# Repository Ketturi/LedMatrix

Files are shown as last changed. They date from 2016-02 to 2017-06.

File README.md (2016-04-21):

# LedMatrix
128x10 LED matrix IoT display.

ESP8266 WiFi module controls daisychained 32x10 led display units.
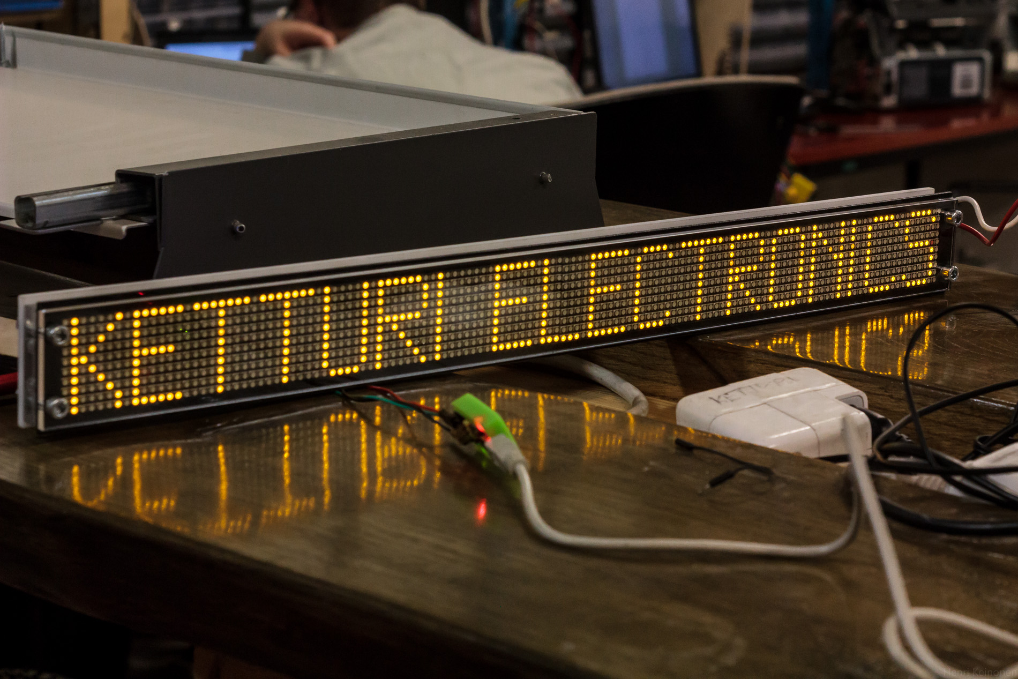
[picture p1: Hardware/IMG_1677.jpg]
Display


## Hardware
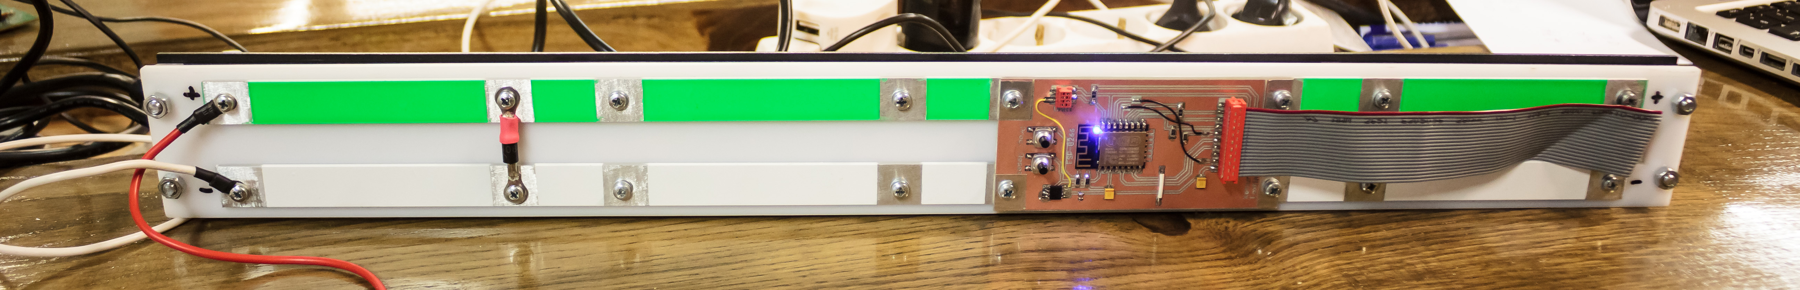
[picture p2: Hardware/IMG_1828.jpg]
Display Backside

Custom build enclosure to hold four display modules, their interlinking cables, power busbars and controller board together. Acrylic parts are lasercut from dxf images designed in Autodesk Fusion360.
[3D CAD Model in A360](http://a360.co/1Sen1dj).

[Control board](https://github.com/Ketturi/LedMatrix/tree/master/Hardware/ControlPCB) for connectinc ESP8266 module to display modules is designed in eagle and is made by milling it with CNC routter. 
Display modules are connected to ESP8266 with high speed SPI for matrix column data, and 4 parallel lines for matrix row address.
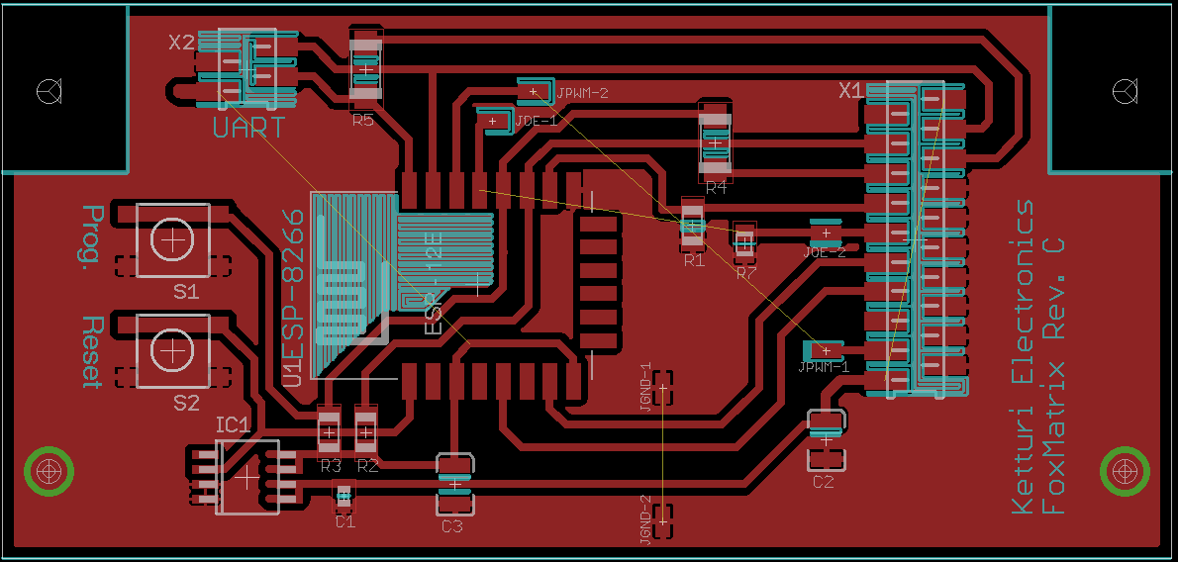
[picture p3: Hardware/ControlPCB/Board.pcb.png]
Control board

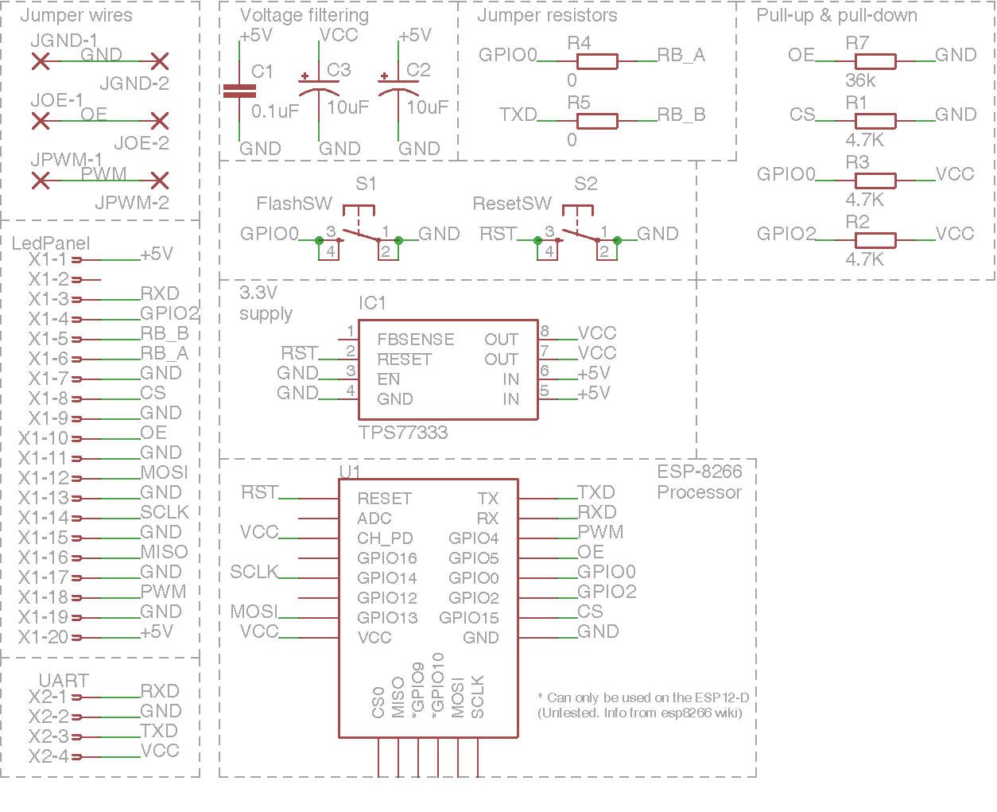
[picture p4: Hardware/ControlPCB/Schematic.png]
Schematics

Display modules used in this single prototype are propriety, and do not contain make or model. There is no other available information of these, and all work here is done trough reverse engineering.
Code and control board is easily adaptable to publicly obtainable LED matrix displays.

## Software
ESP8266 module runs arduino sketch. Arduino IDE needs [Board core files](https://github.com/esp8266/Arduino) to be able to compile software for module.
Use the arduino.org IDE 1.7.9! Arduino.cc IDE is not working due issues with arduino-builder. You need to install board files and libraries manually.

Simple function converts binary bitmap data to column data corresponding selected row and column. Data is then transferred trough SPI to column led drivers (32 bit shift register in each module daisychained together)
Row is selected trough 4-bit address. 

### ESP8266 spesific features
#### OTA Update
Software incorporates [OTA updates](http://esp8266.github.io/Arduino/versions/2.1.0/doc/ota_updates/ota_updates.html) through Arduino IDE. When ESP8266 is connected to same network as computer containing IDE, board shows in port menu.
#### WiFi Manager
ESP8266 uses [WiFi Manager](https://github.com/tzapu/WiFiManager) library that allows modifying wlan credentials and other settings without recompiling and uploading the software.
When control board is powered, it tries to connect previously saved WiFi access point. If that however fails, ESP8266 creates access point itself. By connecting this access point user can go to http://192.168.4.1 address and input their own WiFi credentials.
Credentials are saved to flash, and ESP8266 tries to connect that access point. After successful connection display is initialized and starts to show data.
### Arduino IDE board settings

| Setting | Option | Explanaition |
| --- | --- |  --- |
| Board | Generic ESP8266 Module |Install board from http://github.com/esp8266/Arduino
| Flash Mode | QIO |Selects how flash is controlled, QIO = 4 data lines
| Flash Size | 4M (1M SPIFFS) |4MB flash IC, 1M file system (3MB for scetch&OTA)
| Debug port | Disabled |Disables serial debug, serial lines used for data lines
| Debug level | None |No debuging
| Reset Method | ck |Does not matter, no serial programming reset ability
| Flash Frequency | 40Mhz |Probably 40Mhz, 80Mhz should be carefully tested
| Upload Using | OTA |Updated over network
| CPU Frequency | 160Mhz |Speed boost for faster display
| Upload SPEED | 115200| Does not matter when using OTA
| Port | FoxMatrix at <ip> (Generic ESP8266 Module) |Select device from network, shows only when properly connected and discovered

###Kukkaconvert
Kukkaconvert.exe is small windows command line utility for converting PNG images to bitmap binary data for display.
"kukkaconvert.exe image.png" accepts 12 pixel high png black and white images and outputs binary data to output.txt file.

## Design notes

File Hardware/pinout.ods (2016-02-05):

1 | Logic Supply | 5V+ out
2 | ??? | N/C
3 | 1G1+2G2A | Multiplex bit 4 | Rows 0-11
4 | C | Multiplex bit 3 | 1-10 usable
5 | B | Multiplex bit 2
6 | A | Multiplex bit 1
7 | GND
8 | Latch Enable | Shift register chain
9 | GND | 32 bits per board.
10 | Output Enable | 128 bits per 4 boards.
11 | GND
12 | Serial data in
13 | GND
14 | Clock
15 | GND
16 | Feedback | Serial out from last panel
17 | GND
18 | Intensity | PWM
19 | GND
20 | Logic Supply | 5V+ out

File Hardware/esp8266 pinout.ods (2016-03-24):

GPIO | Assigned | Boot function | Function
0 | RB_A | BOOT FLASHSW | FUNCTION_0
1 | RB_B | TXD BOOT | FUNCTION_3
2 | RB_C | BOOT HIGH | FUNCTION_0
3 | RB_D | RXD BOOT | FUNCTION_3
4 | PWM |  | FUNCTION_0
5 | OE |  | FUNCTION_0
6 | Unusable
7 | Unusable
8 | Unusable
9 | Unusable
10 | Unusable
11 | Unusable
12
13 | HSPI MOSI |  | FUNCTION_2
14 | HSPI SCLK |  | FUNCTION_2
15 | HSPI CS | BOOT HIGH | FUNCTION_2
16

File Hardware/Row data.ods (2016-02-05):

Data / Out | 0 | 1 | 2 | 3 | 4 | 5 | 6 | 7 | 8 | 9 | 10 | 11 | 12 | 13 | 14 | 15 | Rivi
0 | H | H | H | H | X | X | X | X | L | H | H | H | H | H | H | H | 1 | Missing leds
1 | H | H | H | H | X | X | X | X | H | L | H | H | H | H | H | H | 2 | first row
10 | H | H | H | H | X | X | X | X | H | H | L | H | H | H | H | H | 3
11 | H | H | H | H | X | X | X | X | H | H | H | L | H | H | H | H | 4
100 | H | H | H | H | X | X | X | X | H | H | H | H | L | H | H | H | 5
101 | H | H | H | H | X | X | X | X | H | H | H | H | H | L | H | H | 6
110 | H | H | H | H | X | X | X | X | H | H | H | H | H | H | L | H | 7
111 | H | H | H | H | X | X | X | X | H | H | H | H | H | H | H | L | 8
1000 | L | H | H | H | X | X | X | X | H | H | H | H | H | H | H | H | 9
1001 | H | L | H | H | X | X | X | X | H | H | H | H | H | H | H | H | 10
1010 | H | H | L | H | X | X | X | X | H | H | H | H | H | H | H | H | 11 | last row
1011 | H | H | H | L | X | X | X | X | H | H | H | H | H | H | H | H | 12 | Missing leds
1100 | H | H | H | H | X | X | X | X | H | H | H | H | H | H | H | H
1101 | H | H | H | H | X | X | X | X | H | H | H | H | H | H | H | H
1110 | H | H | H | H | X | X | X | X | H | H | H | H | H | H | H | H
1111 | H | H | H | H | X | X | X | X | H | H | H | H | H | H | H | H

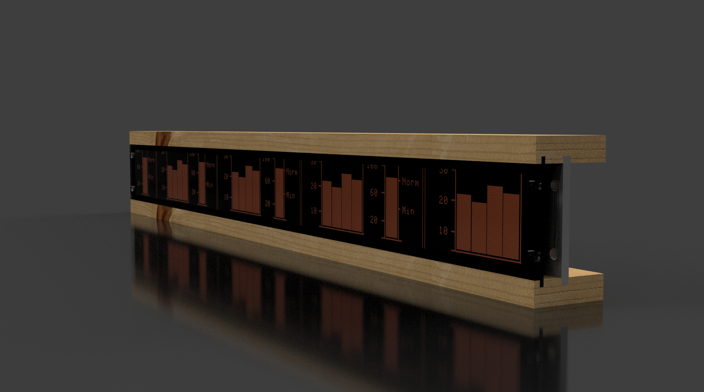
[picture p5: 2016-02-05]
Hardware/Case/Led matrix v2.png

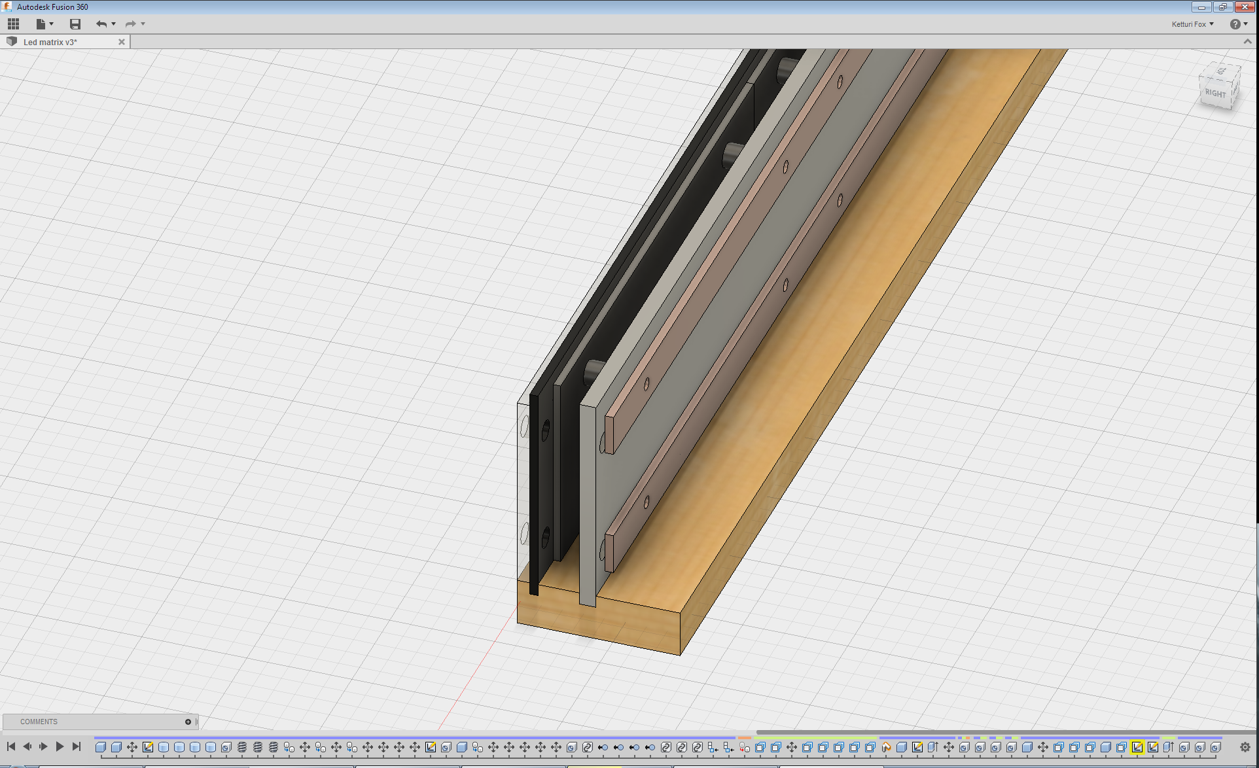
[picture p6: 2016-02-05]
Hardware/Case/Screenshot 2016-01-26 11.06.32.png

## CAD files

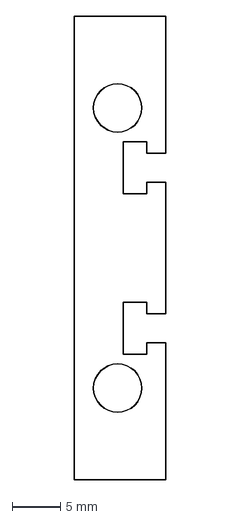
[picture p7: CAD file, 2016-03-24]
Hardware/Case/Spacer.dxf
9.50 x 48.0 mm

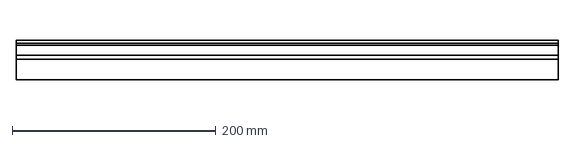
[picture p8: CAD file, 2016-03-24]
Hardware/Case/Board.dxf
532.0 x 38.8 mm

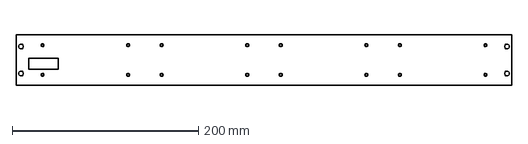
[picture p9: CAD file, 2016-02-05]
Hardware/Case/Back plate.dxf
532.0 x 54.0 mm

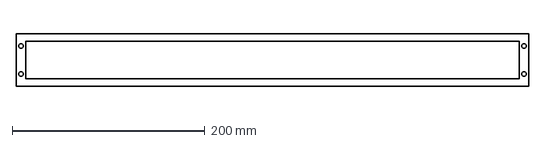
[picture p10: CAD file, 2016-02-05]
Hardware/Case/Mid plate.dxf
532.0 x 54.0 mm

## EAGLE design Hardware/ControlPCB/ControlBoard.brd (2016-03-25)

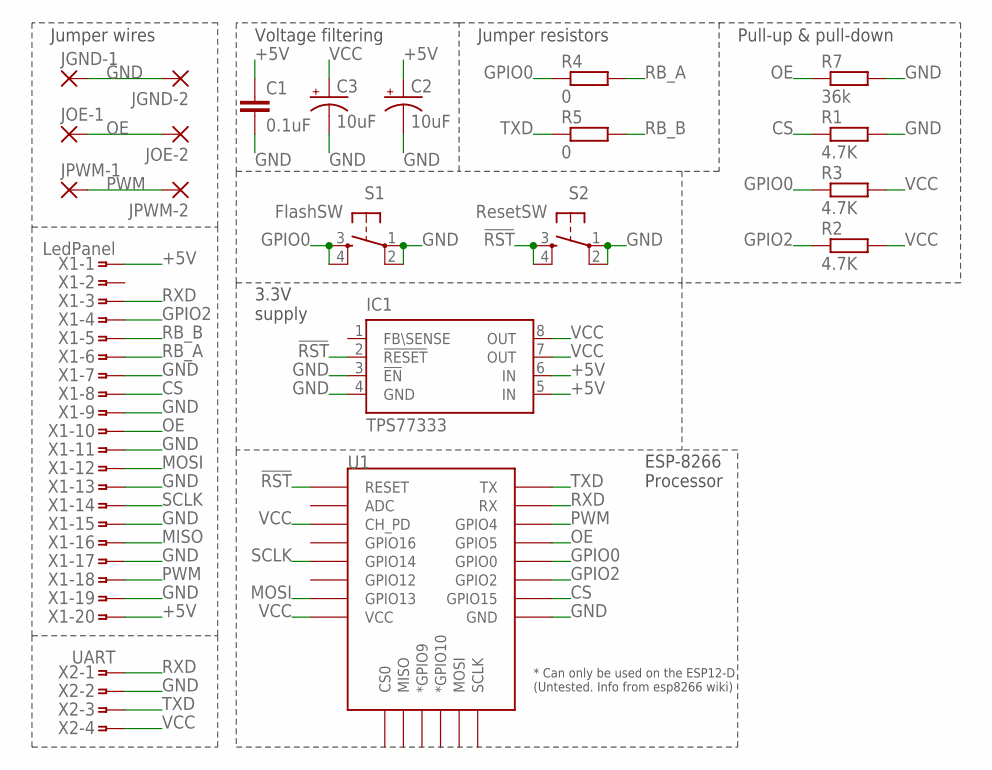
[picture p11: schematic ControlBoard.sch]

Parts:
C1: 0.1uF; 0603-CAP
C2, C3: 10uF; EIA3528
IC1: TPS77333; SOP-08
JGND-1, JGND-2: SMD2; SMD1,27-2,54
JOE-1, JOE-2: SMD2; SMD1,27-2,54
JPWM-1, JPWM-2: SMD2; SMD1,27-2,54
R1, R2, R3: 4.7K; R1206
R4, R5: 0; R5025W
R7: 36k; M2012
S1: FlashSW; DTSM-6
S2: ResetSW; DTSM-6
U1: ESP12ESMD; ESP12E-SMD
X1: LedPanel; SMDTOP20
X2: UART; SMDTOP4

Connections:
!RST: IC1.2 (!RESET), S2.3, S2.4, U1.RESET
+5V: C1.1, C2.A (+), IC1.5 (IN), IC1.6 (IN), X1.1, X1.20
CS: R1.1, U1.GPIO15, X1.8
GND: C1.2, C2.C (-), C3.C (-), IC1.3 (!EN), IC1.4 (GND), JGND-1.1, JGND-2.1, R1.2, R7.2, S1.1, S1.2, S2.1, S2.2, U1.GND, X1.7, X1.9, X1.11, X1.13, X1.15, X1.17, X1.19, X2.2
GPIO0: R3.1, R4.1, S1.3, S1.4, U1.GPIO0
GPIO2: R2.1, U1.GPIO2, X1.4
MISO: X1.16
MOSI: U1.GPIO13, X1.12
OE: JOE-1.1, JOE-2.1, R7.1, U1.GPIO5, X1.10
PWM: JPWM-1.1, JPWM-2.1, U1.GPIO4, X1.18
RB_A: R4.2, X1.6
RB_B: R5.2, X1.5
RXD: U1.RXD0 (RX), X1.3, X2.1
SCLK: U1.GPIO14, X1.14
TXD: R5.1, U1.TXD0 (TX), X2.3
VCC: C3.A (+), IC1.7 (OUT), IC1.8 (OUT), R2.2, R3.2, U1.CH_PD, U1.VCC, X2.4

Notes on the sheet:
Jumper wires
Voltage filtering
Jumper resistors
Pull-up & pull-down
3.3V supply
ESP-8266 Processor

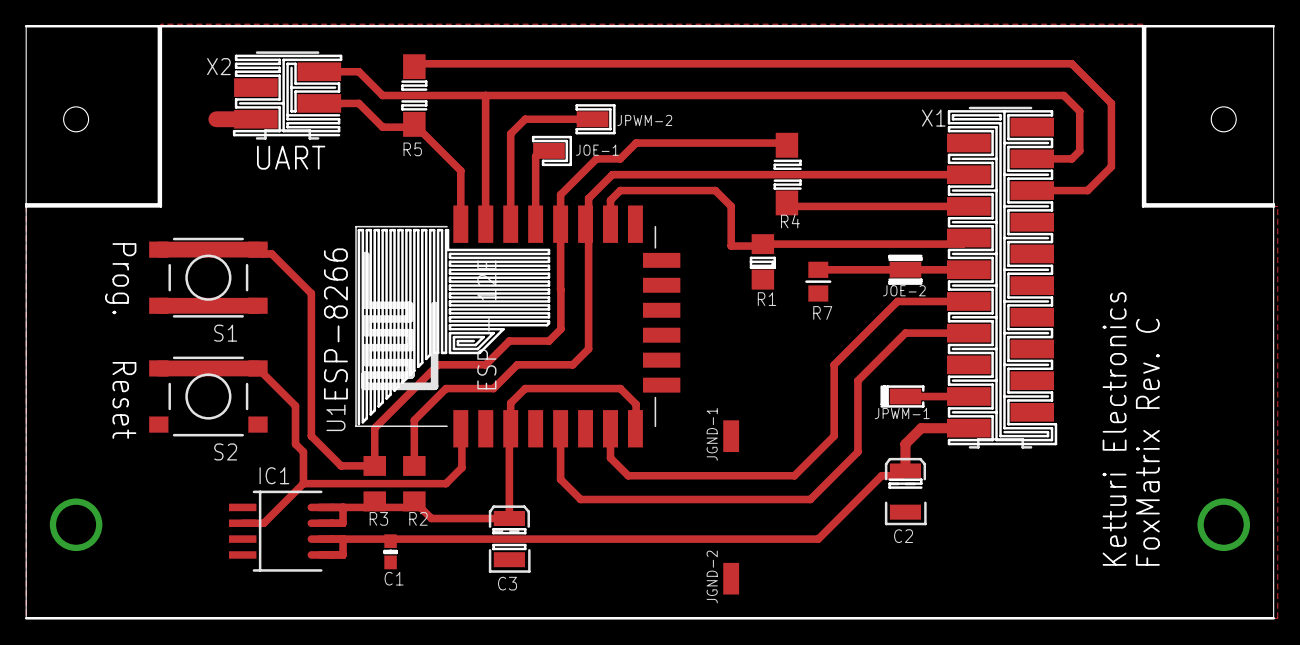
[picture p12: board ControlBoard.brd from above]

Board: 2 copper layers, 100.0 x 47.5 mm, 21 parts (0 on the bottom side), 15 nets.

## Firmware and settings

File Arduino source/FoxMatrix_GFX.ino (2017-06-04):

/*Led matrix IoT controller
  128x10 (four 32x10 linked modules) led matrix display
  controlled with 4bit row select lines and 32bit line shift register.
  ESP8266 (ESP-12F module) as internet enabled application processor
  http://esp8266.github.io/Arduino/versions/2.1.0/doc/reference.html
  Ketturi 2016
*/

#include <Arduino.h>
extern "C" {
#include "user_interface.h"
}
#include <Adafruit_GFX.h>
#include "display.h" //FoxMatrix LED display library

//Font for display
#include "FoxFont.h"
#define font &FoxFont
#define textPos 9 //Vertical position for font

//Bitmaps for symbols
#include "Bitmaps.h"

//Configure display
FoxMatrix screen(10, 128, false); //(height, width, double_buffering)

//Interrupt for display refresh, needs to be polled often
os_timer_t updateTimer;
void ICACHE_RAM_ATTR INT_handler(void *pArg) {
  screen.updateDisplay();
}

#include <Ticker.h> //Ticker for scheduling display stuff
Ticker scheduler;
Ticker busupdater;
Ticker message;

int count = 0;
int page = 0;
bool msgWait = false;
int lastpage = 2;
int pageDelay = 10; //Seconds between display page changes

#define NYSSEPAGE 1
#define CLOCKPAGE 0
#define HEAPPAGE 2

//NTP time
#define NTP_ADDRS "172.20.1.1" //Local NTP server, it's polled quite often so public NTP is not to be used if possible
#include <TimeLib.h>
#include <NtpClientLib.h>

#include "wifi_handler.h"
#include "busstop.h"

BusStop nysse("0501"); //Calls TKL api and sets monitored stop.
int nyssescroller = 0;

void setup() {
  pinMode(16, SPECIAL); //Set GPIO16 to default function, controls reset

  screen.begin(); //Starts display routine

  screen.selectRow(2); //Debug, tells that display is initialized
  delay(100);

  screen.fillScreen(0); //Empty buffer

  os_timer_setfn(&updateTimer, INT_handler, NULL); //set sw timer interupt callback
  os_timer_arm(&updateTimer, 2, true); //Start timer, at this time display starts to show data from framebuffer

  screen.setTextWrap(false);

  screen.setTextSize(1);
  screen.setFont(font);
  screen.setTextColor(1);
  screen.setCursor(0, textPos);
  screen.print("ESP8266 WifiDisplay");

  delay(1000);

  //Wifi
  WiFi.persistent(true);
  setWiFi(); //Starts wifi routines
  wificallbacks(); //Enables wifi messages to display
  otaUpdate(); //Enable ota updates

  NTP.begin(NTP_ADDRS, 2, true); //Initializes NTP connection
  NTP.setInterval(600); //Update NTP time every 10 minutes (ESP8266 is inaccurate at timekeeping)
  ntpCallback(); //Enables NTP messages on screen

  screen.setCursor(0, textPos);
  scheduler.attach(10, changePage);
  busupdater.attach(60, updateBusData);
  nysse.updateBuffer();
}

void loop() { //loops constantly
  ArduinoOTA.handle();

  while ( WiFi.status() == WL_CONNECTED) {
    if (msgWait == false) {
      switch (page) {
        case HEAPPAGE:
          screen.fillScreen(0);
          screen.drawBitmap(0, 0, BitmapInfo, 16, 10, 1);
          screen.setCursor(12, textPos);
          screen.print("Free heap: ");
          screen.print(system_get_free_heap_size());
          screen.print("B");
          break;
        case NYSSEPAGE:
          screen.fillScreen(0);
          screen.drawBitmap(0, 0, BitmapBus, 16, 10, 1);
          screen.setCursor(12, textPos);
          screen.print("Bus ");
          screen.print(nysse.returnLine(nyssescroller));
          screen.drawBitmap(44, 0, BitmapClock, 16, 10, 1);
          screen.setCursor(56, textPos);
          screen.print((nysse.returnTime(nyssescroller) - now()) / 60);
          screen.print(" min");
          break;
        case CLOCKPAGE:
          screen.fillScreen(0);
          screen.drawBitmap(0, 0, BitmapClock, 16, 10, 1);
          screen.setCursor(12, textPos);
          screen.print(NTP.getTimeStr());
          screen.drawBitmap(54, 0, BitmapCalendar, 16, 10, 1);
          screen.setCursor(66, textPos);
          screen.print(NTP.getDateStr());
          break;
        case 3:
          screen.fillScreen(0);
          screen.setCursor(0, textPos);
          screen.print(now());
          screen.print("s since epoch");
          break;

      }

      screen.swapBuffers(false); //Bring backbuffer to display
      yield(); //Run background functions
    }
  }
  screen.swapBuffers(false); //Bring backbuffer to display
  yield();
}

void ntpCallback() {
  NTP.onNTPSyncEvent([](NTPSyncEvent_t ntpEvent) {
    if (ntpEvent) {
      msgWait = true;
      screen.fillScreen(0);
      screen.drawBitmap(0, 0, BitmapWarn, 16, 10, 1);
      screen.setCursor(12, textPos);
      screen.print("NTP error: ");
      if (ntpEvent == noResponse)
        screen.print("Server not reachable");
      else if (ntpEvent == invalidAddress)
        screen.print("Invalid address");
    }
    else {
    }
  });
}

void changePage() {
  if (msgWait == false) {
    if (nysse.bufferSize() != 0 && page == NYSSEPAGE) {
      if (nyssescroller == nysse.bufferSize() - 1) {
        nyssescroller = 0;
        page++;
      }
      else
        nyssescroller++;
    }
    else {
      if (page == lastpage)
        page = 0;
      else {
        page++;
        if (page == NYSSEPAGE && nysse.bufferSize() == 0) {
          page++;
        }
      }
    }
  }

  else {
    scheduler.detach();
    msgWait = false;
    message.once(5, startScheduler);
  }
}

void updateBusData() {
  nysse.updateBuffer(); //Downloads lastest stuff
}

void startScheduler() {
  scheduler.attach(pageDelay, changePage);
}

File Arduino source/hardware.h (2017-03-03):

/*
   Hardware definitions for LED matrix with ESP8266 ESP-12F target.
   http://www.electrodragon.com/w/ESP-12F_ESP8266_Wifi_Board
   https://github.com/Ketturi/LedMatrix/tree/master/Hardware
*/

/*ArduinoIDE settings:
   Board: "Generic ESP8266 Module" //Install board from http://github.com/esp8266/Arduino
   Flash Mode: "QIO"               //Selects how flash is controlled, QIO = 4 data lines
   Flash Size: 4M (1M SPIFFS)"     //4MB flash IC, 1M file system (3MB for scetch&OTA)
   Debug port: "Disabled"          //Disables serial debug, serial lines used for data lines
   Debug level: "None"             //No debuging
   Reset Method: "ck"              //Does not matter, no serial programming reset ability
   Flash Frequency: "40Mhz"        //Probably 40Mhz, 80Mhz should be carefully tested
   Upload Using: "OTA"             //Updated over network
   CPU Frequency: "160Mhz"         //Speed boost for faster display
   Upload SPEED: "115200"          //Does not matter when using OTA
   Port: "FoxMatrix at <ip> (Generic ESP8266 Module) //Select device from network, shows only when properly connected and discovered
*/

//Shift register pins
#define latchPin  15  //SS/CS  SPI Chip Select
#define clockPin  14  //SCLK   SPI Clock
#define dataPin   13  //MOSI   SPI Data out
#define enablePin  4  //OE     Enables output driver when low, prevents ghosting while data is loaded
#define pwmPin     5  //PWM    For led driver current control, 255 gives 2A/panel!
#define SPISPEED 25000000 //Input as Hz, 25Mhz for 128bit display, higher speeds corrupts data

const int rowAdrsPin[] = {0, 1, 2, 3}; //Row decoder pins, 0-11 dec values corresponds lines, 1-10 usable as 0 and 11 lines are missing all leds

#define ledColumns 128 //How many pixels in one row
#define firstRowAdrs 1 //first row address, 1 for 10 row display, 0 for 12 row display
#define lastRowAdrs 10 //last row address, 10 for 10 row display, 11 for 12 row display

#define DISPLAYWIDTH 128 //lenght of display in bits
#define DISPLAYHEIGHT 10 //row count of display
unsigned int rowOnTime = 100; //Time that leds are lit
byte pwm = 120; //initial led drive current.

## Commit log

2016-02-03 First test arduino scetch
2016-02-05 Misc files
    [Back plate.dxf, Mid plate.dxf, Row data.ods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]
2016-02-17 Faster SPI implementation
2016-03-05 Target changed to ESP8266
    Target MCU is now ESP8266 wifi enabled chip. Eagle board files and
    schematic for cnc routed prototype board and updated arduino code that
    compiles for ESP8266.
    [Board.dxf, ControlBoard.brd, ControlBoard.sch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]
2016-03-22 Some PCB changes
    [ControlBoard.brd, ControlBoard.sch]
2016-03-24 Updated schematics and pcb
    Cleaned up schematics and new board layout with milling code files.
    [ControlBoard.brd, ControlBoard.sch]
2016-03-25 Added documentation
    Better comments in source code. Schematic and board layout as images.
    [ControlBoard.brd]
2016-04-18 Dirty Fix for arduino builder bug
    Had to flip whole structure upside down because this piece of ****:
    https://github.com/arduino/arduino-builder/issues/68
    https://github.com/arduino/arduino-builder/issues/80
    https://github.com/arduino/arduino-builder/issues/85 and countless other
    issue tickets, arduino builder preprocessor fails to do prototype and
    can't reorder functions so everything must be just in the right order
    (and also breaks many libraries and other third party boards). Code may
    not compile properly as long as arduino developpers can't get their ****
    together. Wifi part won't work until underlying issue in arduino-builder
    gets fixed or old version of arduino ide is used or something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
    [hardware.h]
2016-04-21 More bitmaps and arduino scetch
    Added some nice bitmaps for demostration. Included arduino scetch that
    WORKS with arduino.ORG IDE 1.7.9!
    Use arduino.org's version of IDE, as arduino.cc's IDE is broken and sad.
    [hardware.h]
2017-03-03 Moving to Adafruit_GFX library and dynamic display framebuffer
    Rewrote whole code, now in FoxMatrix class that can be used as library
    for driwing display. Added Adafruit_GFX library support and implemented
    memory mapped framebuffer with option for double buffering.

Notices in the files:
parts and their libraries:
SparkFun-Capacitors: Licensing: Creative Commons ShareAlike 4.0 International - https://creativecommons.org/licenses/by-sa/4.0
